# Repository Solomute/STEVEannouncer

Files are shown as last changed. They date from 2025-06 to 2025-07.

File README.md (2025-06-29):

If you are here you have probably opened up one of my announce boxes and are trying to fix it.

The buttons and potentiometers are connected to the board via JST PH 2mm headers. You can buy pre-terminated PH cables from many electronics suppliers, including Amazon. JST makes many models of connector, ensure you are buying the PH.

The buttons are SPST NO. I use a Cherry MX mechanical keyboard switch, the top panel cutout is 0.55" square for a Cherry MX or compatible switch to snap into. Many other brands of mechanical keyboard switches are also designed to snap into the same cutout. Simply search the web for "mechanical keyboard switch."

The potentiometers are 10k linear. Do not use a pot with a value other than 10k. Do not use an "audio" or "log" taper pot. The longest-life pots as of the time of this writing use conductive plastic as the resistance element. Avoid carbon. The front panel cutouts for the pots are sized for a standard 6mm diameter shaft. 1/4" diameter shafts should fit too. For knob compatibility get a pot with a 6mm 18T knurled shaft. If you get some other size, or a flatted-D shaft, you're on your own for knobs.

I used a P160KN-0QD15B10K from TT Electronics, but compatibile parts are available from many manufacturers.

My recommendation is that if you are using these boxes in a production environment, you keep a few extra potentiometers and buttons around pre-wired with JSTs. This way, if a pot or button starts dying, you can swap it out in only a couple of minutes. Maybe even during a commercial break!

No audio flows through the buttons or pots. The box will pass audio with a failed switch. A failed pot will cause the headphone to mute, though in practice, the headphone circuit should keep working flawlessly with pots that are degraded well past the point where they would start sounding "scratchy" if audio were passing directly through them.

XLR Input (female) connectors are Neutrik NC3FAH2. XLR Output (male) connectors are Neutrik NC3MAH. 1/4" TRS headphone connectors are Neutrik NRJ6HF. The DC power input is Switchcraft L721RALP.

Neutrik makes many connectors which are electrically and mechanically compatible with the above, and they all should work. For an alternative to the Switchcraft part, you could use a panel-mounted barrel jack and simply run wires off it into the PCB if necessary.

I strongly recommend a *threaded* barrel jack, and power supplies with *threaded* barrel plugs. Being able to lock the power connector is the reason I used a barrel jack instead of a USB plug for DC power.

For more esoteric repairs, consult the schematics. If THAT Corp or Texas Instruments have gone out of business by the time you read this, God help you. Most other parts on the board are generic, but hi-fi audio parts and switching regulators are hard to multi-source, unfortunately.

Design files for the enclosure are also included - You might be able to get away with 3D printing it, but I recommend using SendCutSend to have it cut and bent out of sheet metal with PCB standoffs inserted. Use 6mm M3x0.5 standoffs. OSHCut is talking about adding hardware insertion to their services, so they might be an option as well by the time you read this.

Good luck!

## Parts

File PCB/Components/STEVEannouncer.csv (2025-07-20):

Reference | Qty | Value | Footprint | Mouser Part Number
C302,C318,C319,C320,C321,C403,C404,C407,C408,C416,C417 | 11 | 100p | Capacitor_SMD:C_0402_1005Metric | 791-0402N101K160CT
C303,C304,C328,C329 | 4 | 470p | Capacitor_SMD:C_0402_1005Metric | 80-C0402C471K5R
C205,C206,C209,C301,C308,C309,C310,C311,C312,C313,C314,C315,C322,C323,C324,C325,C326,C405,C406,C410,C411,C412,C413,C414,C415 | 25 | 100n | Capacitor_SMD:C_0402_1005Metric | 81-GRM155R62A104KE4D
C203,C204 | 2 | 2.2u | Capacitor_SMD:C_0603_1608Metric | 81-GRT188R61H225KE3D
C316,C317,C327 | 3 | 10u | Capacitor_SMD:C_0603_1608Metric | 187-CL10A106KP8NNWC
L201,L202 | 2 | 18u | STEVEannouncer:Inductor 3012 | 652-SRN3015BTA-180M
C207,C208 | 2 | 22u | Capacitor_SMD:C_1206_3216Metric | 791-1206X226K100CT
C305,C306 | 2 | 22u | Capacitor_SMD:CP_Elec_6.3x7.7 | 647-UCD1J220MCL1GS
C307 | 1 | 100u | Capacitor_SMD:C_1206_3216Metric | 81-GRM31CR60J107KE8L
C202 | 1 | 1000u | Capacitor_SMD:CP_Elec_16x17.5 | 667-EEV-FK1H102M
R201,R413 | 2 | 1Meg | Resistor_SMD:R_0402_1005Metric | 603-RC0402FR-7W1ML
R204,R301,R302 | 3 | 10 | Resistor_SMD:R_1206_3216Metric | 652-CR1206-JW-100ELF
R306,R319,R320 | 3 | 100 | Resistor_SMD:R_0402_1005Metric | 652-CR0402FX-1000GLF
R209,R303,R304,R315,R316,R317,R318 | 7 | 1k | Resistor_SMD:R_0402_1005Metric | 708-RMCF0402FT1K00
R403,R404 | 2 | 6.8k | Resistor_SMD:R_0402_1005Metric | 652-CR0402FX-6801GLF
R211,R321,R322,R410 | 4 | 10k | Resistor_SMD:R_0402_1005Metric | 652-CR0402FX-1002GLF
RV401,RV402 | 2 | 10k | STEVEannouncer:Pot | 858-P160KN0QD15B10K
R203,R205,R206,R305,R307,R308,R311,R312,R313,R314,R401,R402,R411,R412 | 14 | 20k | Resistor_SMD:R_0402_1005Metric | 603-RC0402FR-1320KL
R207,R208,R210,R407,R408,R409 | 6 | 80.6k | Resistor_SMD:R_0402_1005Metric | 652-CR0402-FX8062GLF
R202,R309,R310,R405,R406 | 5 | 330k | Resistor_SMD:R_0402_1005Metric | 603-RC0402FR-13330KL
C201,C401,C402,C409 | 4 | 1u/50V | Capacitor_SMD:C_0402_1005Metric | 81-GRM155R61H105KE5D
J201 | 1 | Barrel_Jack_Switch | STEVEannouncer:Barrel Jack | 502-L721RALP
D304,D305,D401,D402,D403,D404,D405 | 7 | BAS716 | Diode_SMD:D_SOD-523 | 771-BAS716-T/R
D301,D307,D308 | 3 | BAS3007 | Package_TO_SOT_SMD:SOT-143 | 726-BAS3007A-RPPE6
Q201 | 1 | BC847 | Package_TO_SOT_SMD:SOT-523 | 621-BC847CT-7-F
Q202 | 1 | BCV49 | STEVEannouncer:SOT-89-3 | 771-BCV49135
J303,J304 | 2 | Conn_01x02 | Connector_JST:JST_PH_B2B-PH-SM4-TB_1x02-1MP_P2.00mm_Vertical | 306-B2BPHSM4TBLFSN
J403,J405 | 2 | Conn_01x03 | Connector_JST:JST_PH_B3B-PH-SM4-TB_1x03-1MP_P2.00mm_Vertical | 306-B3BPHSM4TBLFSN
D202,D203,D306 | 3 | D_Schottky | Diode_SMD:D_SOD-523 | 755-RB510SM-40T2R
D201,D302,D303 | 3 | DFLZ5V6 | Diode_SMD:D_PowerDI-123 | 621-DFLZ5V6-7
FB301,FB302,FB303,FB304,FB401,FB402 | 6 | FerriteBead | Inductor_SMD:L_0402_1005Metric | 673-BBSY100505700Y00
D204 | 1 | LED | LED_SMD:LED_0603_1608Metric | 859-LTST-C191KRKT
U201,U202 | 2 | LV3842 | STEVEannouncer:SOT-23-6 | 595-LV3842XDBVR
J306,J307 | 2 | NC3MAH | STEVEannouncer:NC3MAH | 568-NC3MAH
J301,J401 | 2 | NC3FAH2 | STEVEannouncer:NC3FAH2 | 568-NC3FAH-2
J406,J407 | 2 | NRJ6HF | STEVEannouncer:NRJ6HF | 550-20311
U305 | 1 | OPA202 | Package_TO_SOT_SMD:SOT-23-5 | 595-OPA202IDBVR
U403 | 1 | OPA1622 | STEVEannouncer:OPA1622 | 595-OPA1622IDRCT
U302,U402 | 2 | OPA1678 | STEVEannouncer:WSON-8-1EP_3x3mm_P0.5mm_EP1.2x2mm_ThermalVias | 595-OPA1678IDRGR
B401,B402 | 2 | Plastic Nut |  | 550-1005
SW301,SW302 | 2 | SW_SPST | STEVEannouncer:SW_choc_v1_1u | 540-MX1A-C1NN
U303 | 1 | THAT1512 | Package_SO:SO-8_3.9x4.9mm_P1.27mm | 887-1512S08-U
U304 | 1 | THAT1646 | Package_SO:SO-8_3.9x4.9mm_P1.27mm | 887-1646S08-U
U401 | 1 | THAT2162 | Package_SO:QSOP-16_3.9x4.9mm_P0.635mm | 887-2162Q16-U
U301 | 1 | TMUX6236 | Package_SO:TSSOP-16_4.4x5mm_P0.65mm | 595-TMUX6236PWR

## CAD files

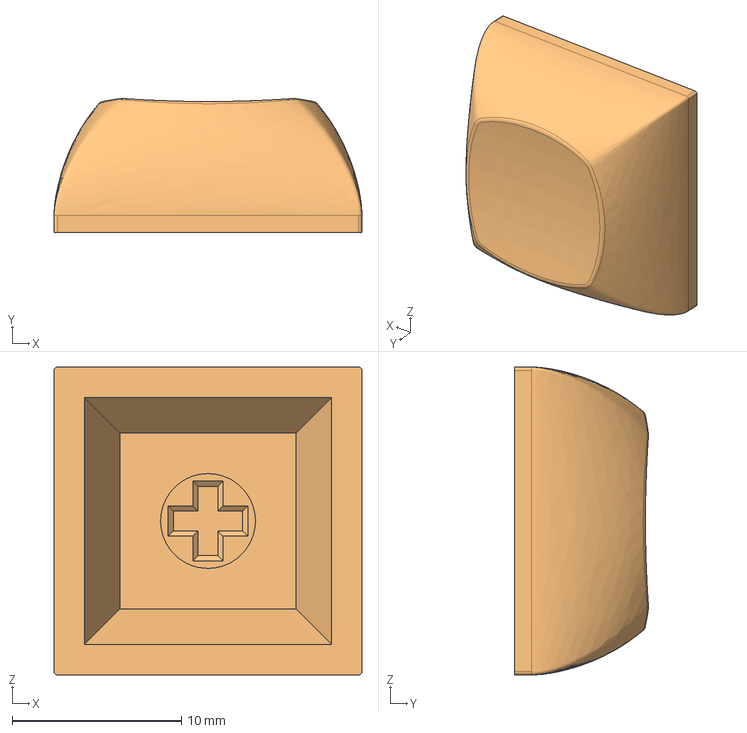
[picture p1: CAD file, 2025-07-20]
Enclosure/DSA_1u.step
18.2 x 7.91 x 18.2 mm

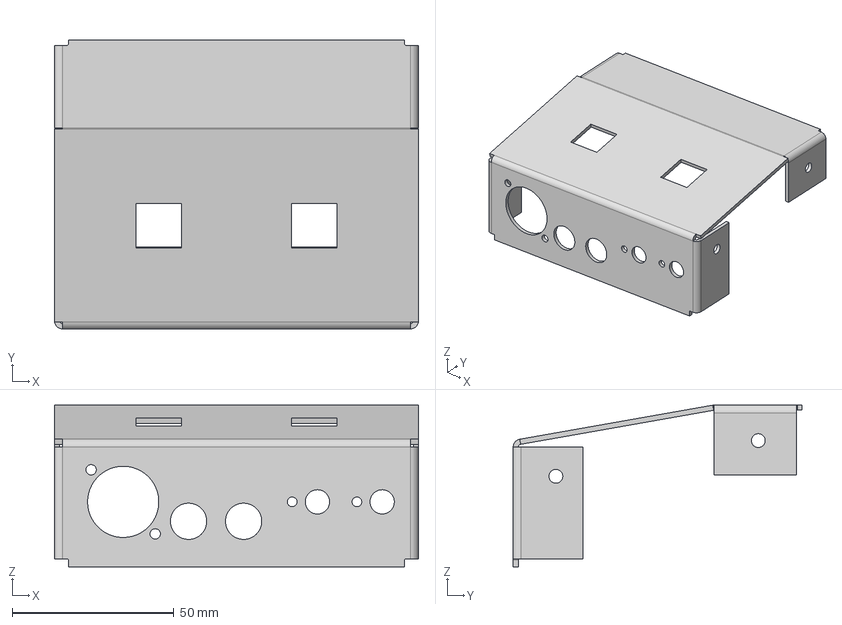
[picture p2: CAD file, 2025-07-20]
Enclosure/Enclosure Top.step
112.4 x 89.2 x 50.0 mm

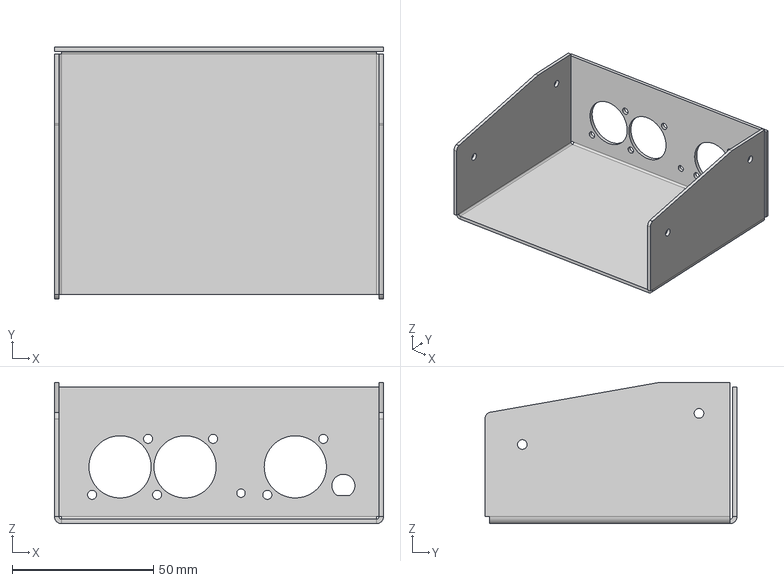
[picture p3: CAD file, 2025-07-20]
Enclosure/Enclosure Bottom.step
116.4 x 89.2 x 50.0 mm

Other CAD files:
Enclosure/Enclosure Bottom.dxf
Enclosure/Enclosure Top.dxf

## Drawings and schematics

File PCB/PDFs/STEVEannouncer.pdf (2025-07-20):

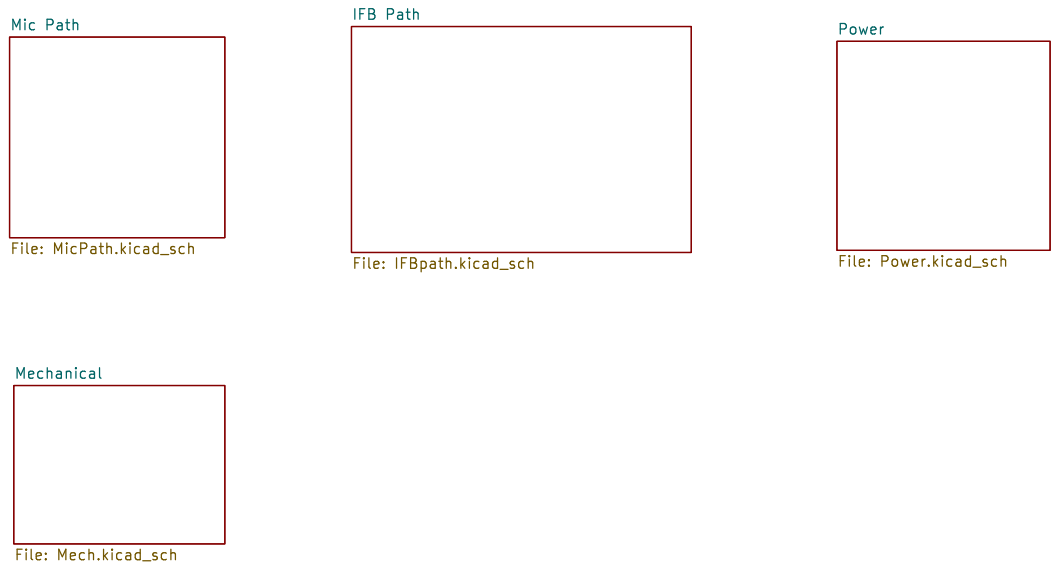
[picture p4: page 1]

Id: 1/5 Title: File: STEVEannouncer.kicad_sch Sheet: / Mechanical File: Mech.kicad_sch

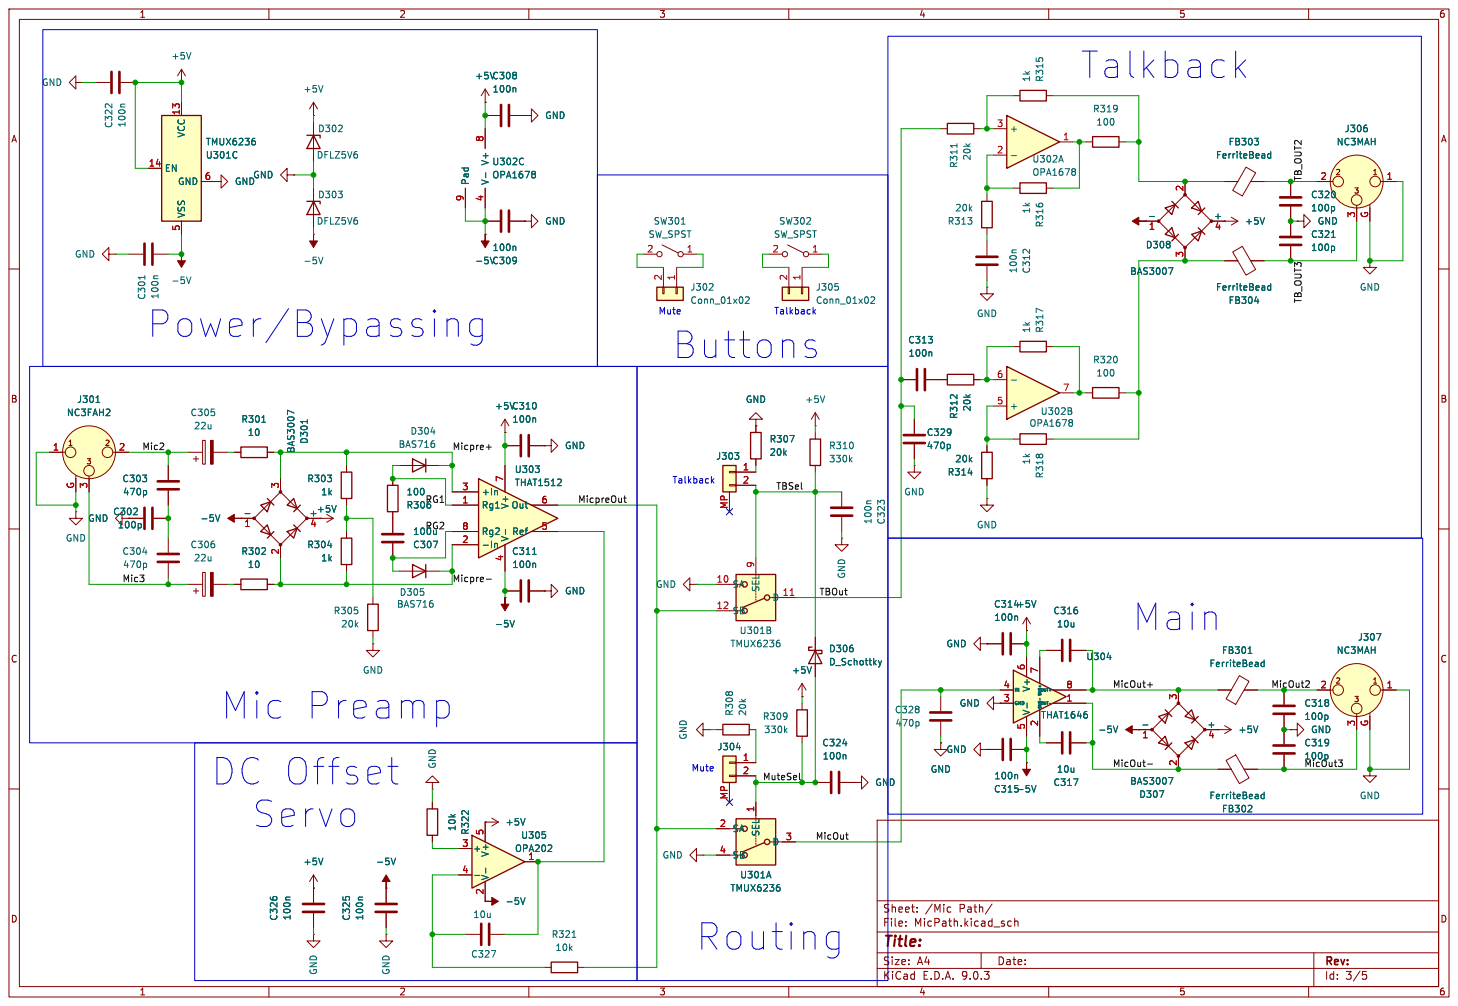
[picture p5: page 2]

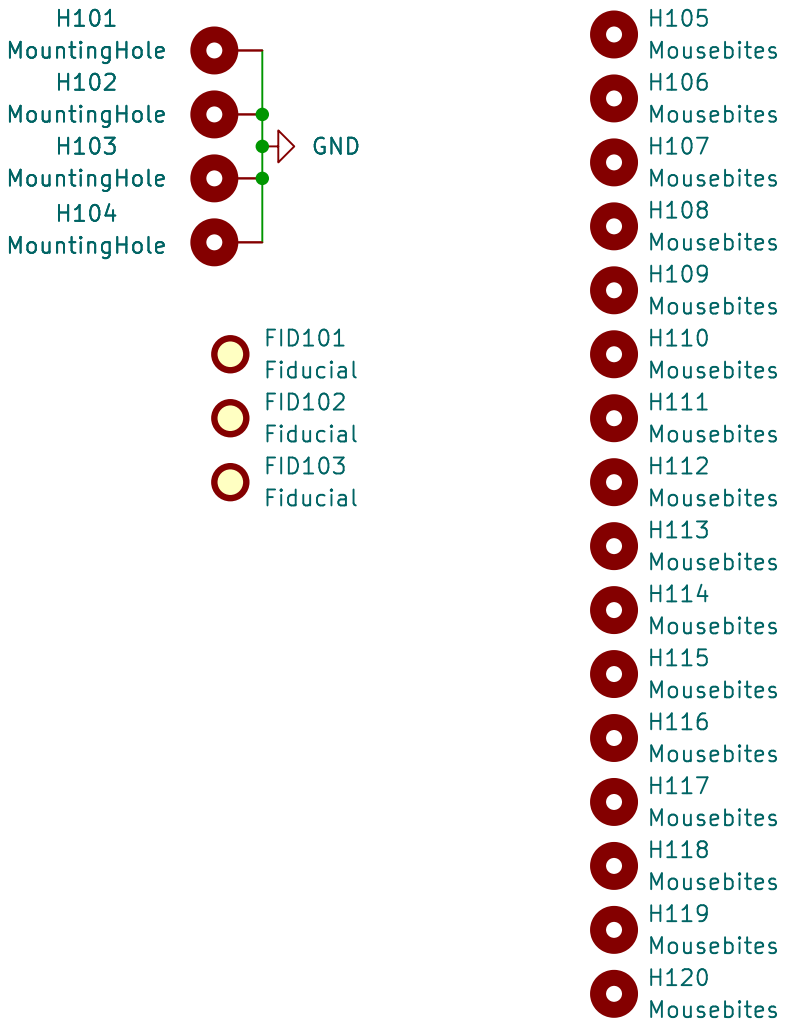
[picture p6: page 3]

H101 MountingHole H104 MountingHole H102 MountingHole H103 MountingHole

Id: 5/5 Title: File: Mech.kicad_sch Sheet: /Mechanical/

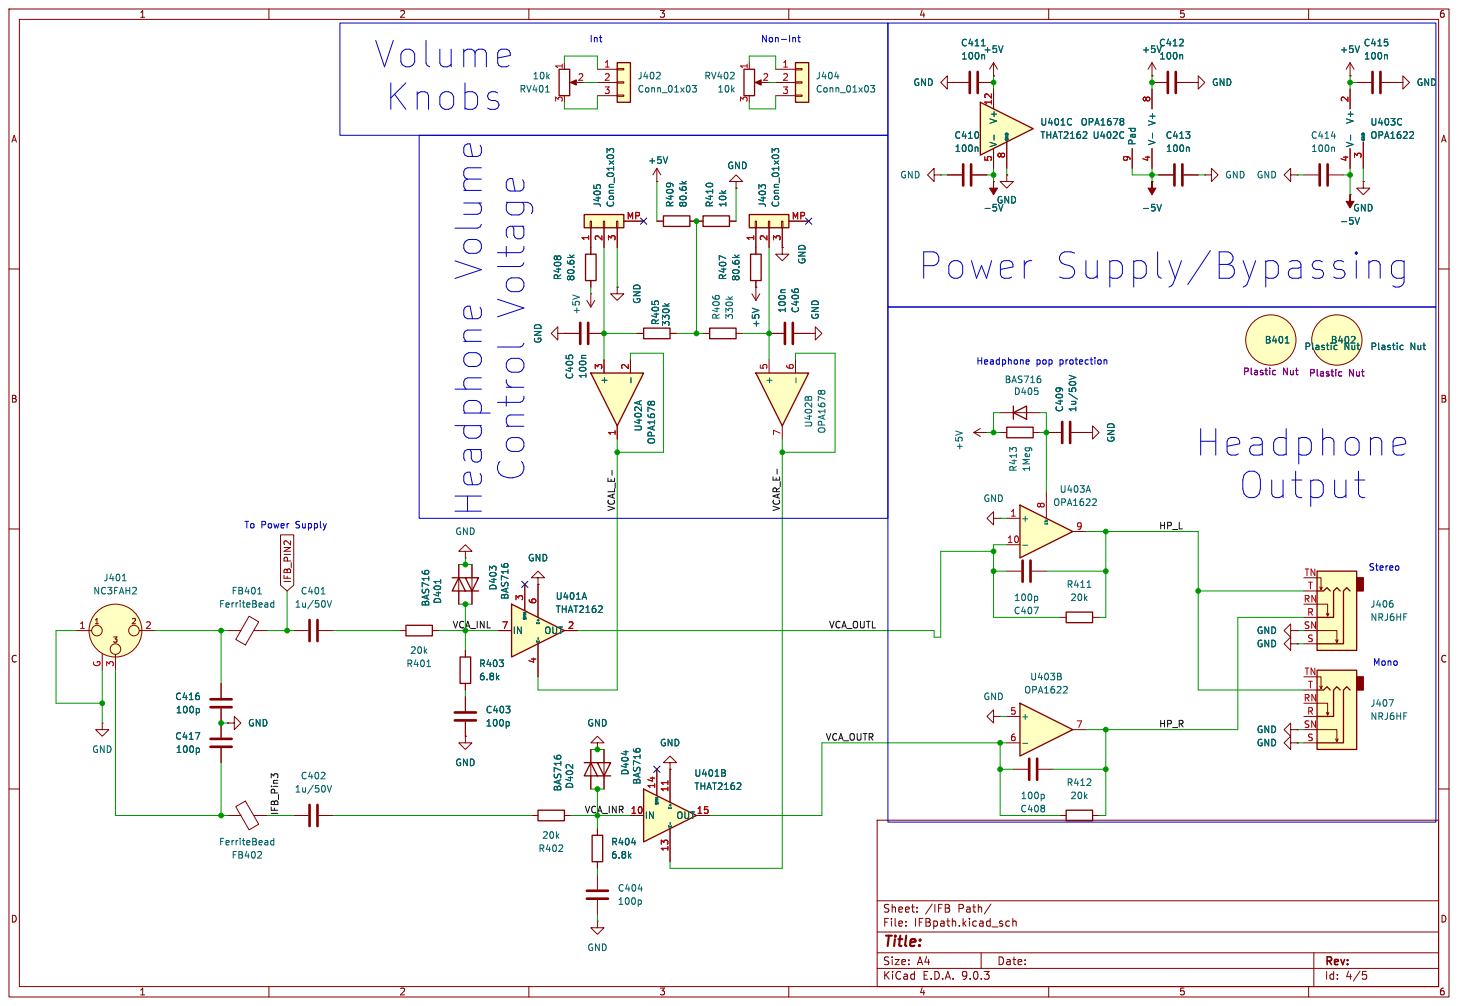
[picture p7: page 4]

Stereo Headphone pop protection Headphone Volume Control Voltage

3 MP GND R410 10k GND GND GND GND

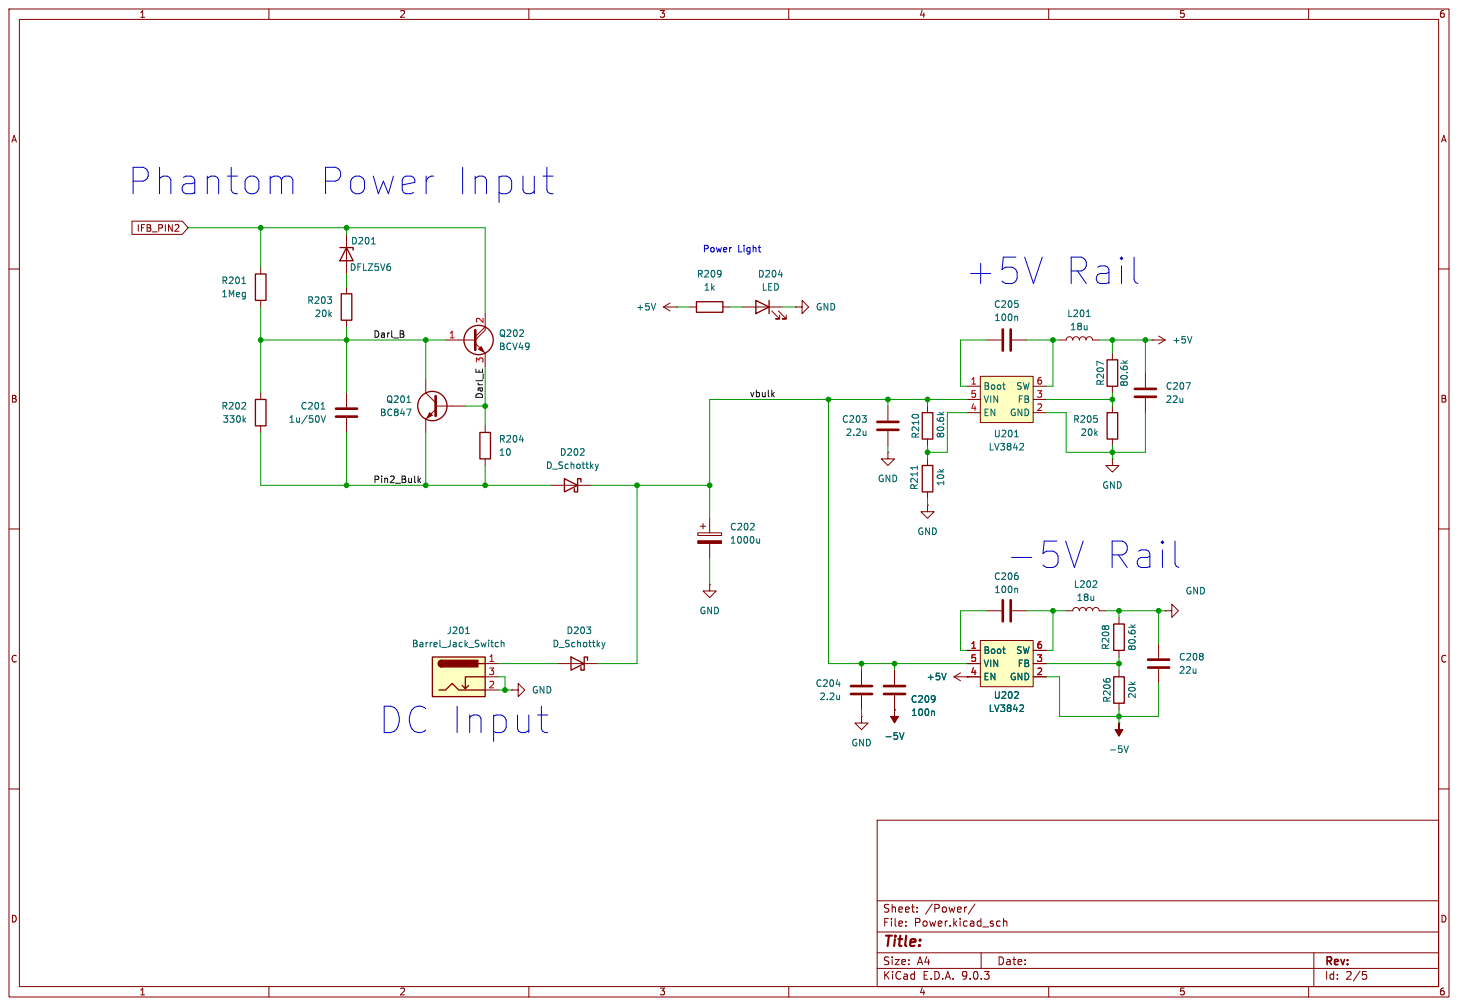
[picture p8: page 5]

2 3 Q202 BCV49 Boot 1 VIN 5 EN 4 SW 6 FB 3 GND 2 U201

Id: 2/5 Title: File: Power.kicad_sch Sheet: /Power/

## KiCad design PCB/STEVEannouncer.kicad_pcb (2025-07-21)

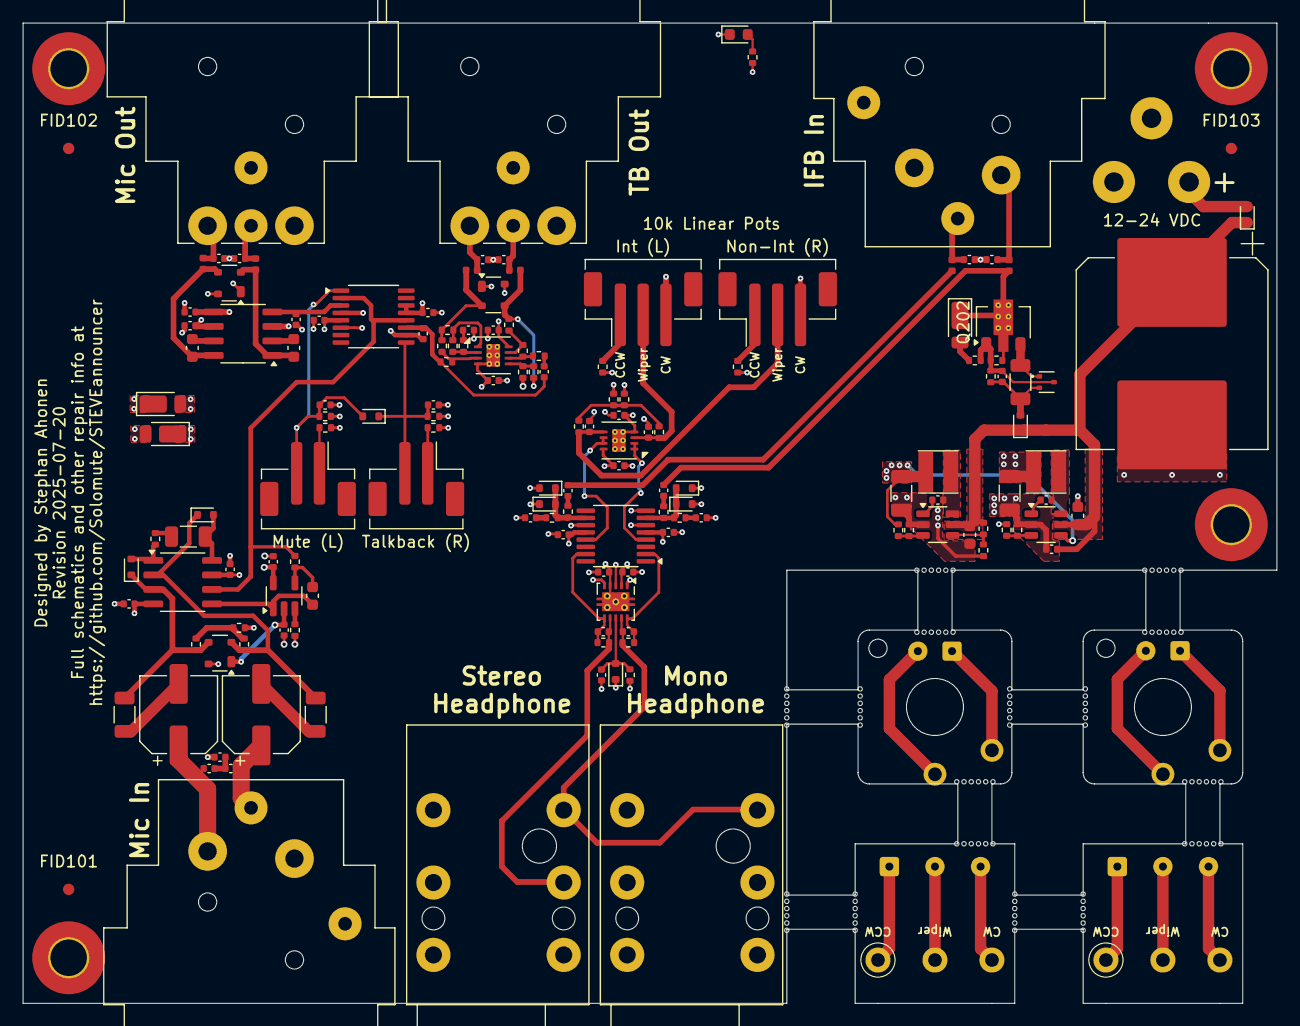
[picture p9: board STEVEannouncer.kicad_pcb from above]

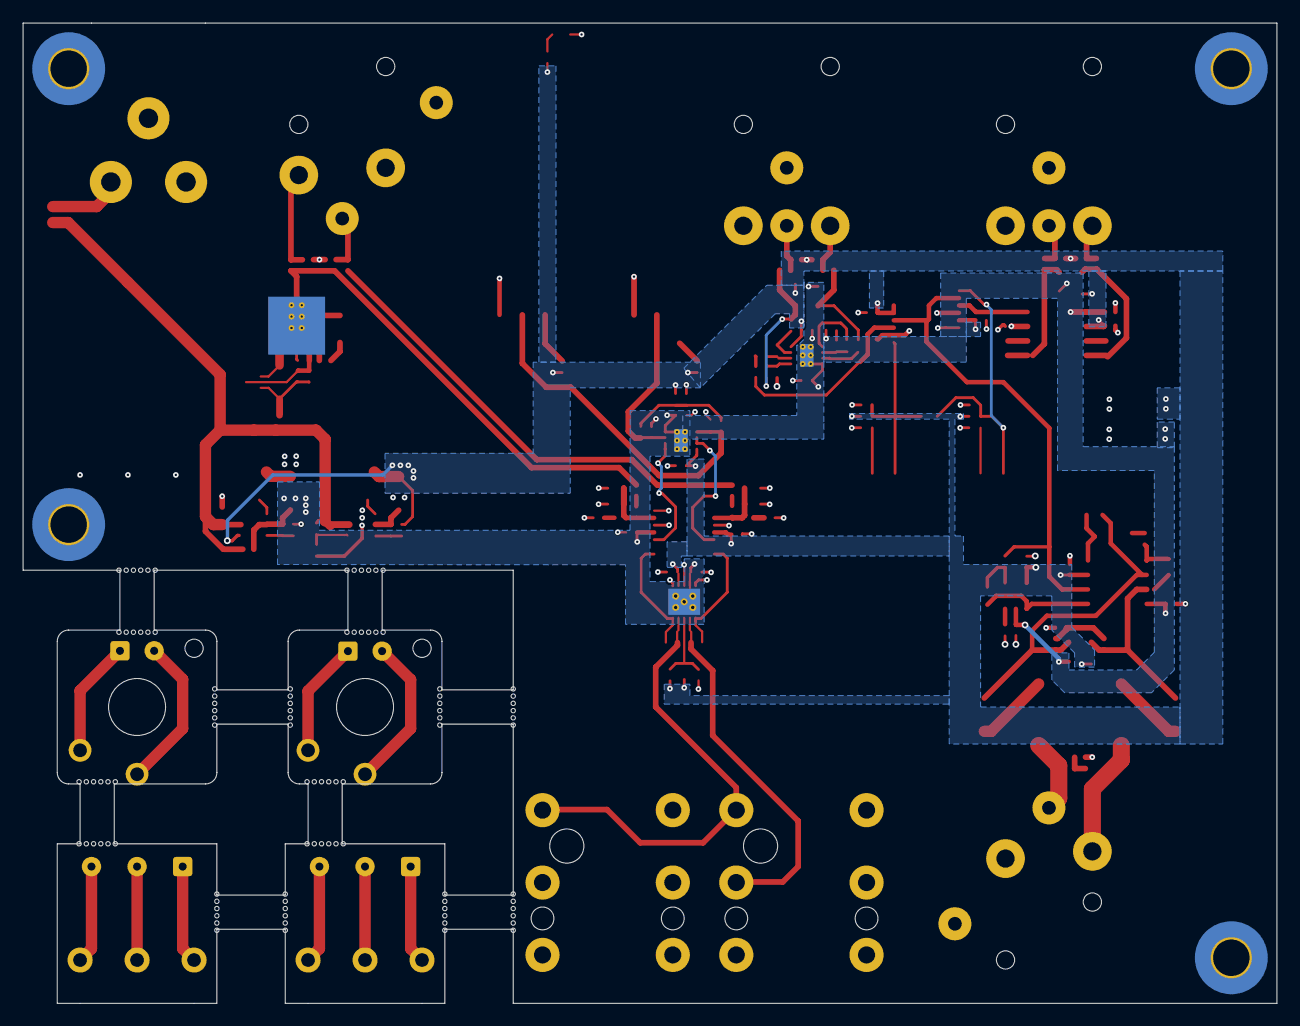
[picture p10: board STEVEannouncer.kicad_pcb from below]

Board: 4 copper layers, 110.0 x 86.0 mm, 180 parts (2 on the bottom side), 88 nets.

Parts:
C201, C401, C402, C409: 1u/50V; C_0402_1005Metric
C202: 1000u; CP_Elec_16x17.5
C203, C204: 2.2u; C_0603_1608Metric
C205, C206, C209, C301, C308, C309, C310, C311, C312, C313, C314, C315, C322, C323, C324, C325, C326, C405, C406, C410, C411, C412, C413, C414, C415: 100n; C_0402_1005Metric
C207, C208: 22u; C_1206_3216Metric
C302, C318, C319, C320, C321, C403, C404, C407, C408, C416, C417: 100p; C_0402_1005Metric
C303, C304, C328, C329: 470p; C_0402_1005Metric
C305, C306: 22u; CP_Elec_6.3x7.7
C307: 100u; C_1206_3216Metric
C316, C317, C327: 10u; C_0603_1608Metric
D201, D302, D303: DFLZ5V6; D_PowerDI-123
D202, D203, D306: D_Schottky; D_SOD-523
D204: LED; LED_0603_1608Metric
D301, D307, D308: BAS3007; SOT-143
D304, D305, D401, D402, D403, D404, D405: BAS716; D_SOD-523
FB301, FB302, FB303, FB304, FB401, FB402: FerriteBead; L_0402_1005Metric
FID101, FID102, FID103: Fiducial; Fiducial_1mm_Mask3mm
H101, H102, H103, H104: MountingHole; MountingHole_3.2mm_M3_Pad_TopBottom
H105, H106, H107, H108, H109, H110, H111, H112, H113, H114, H115, H116, H117, H118, H119, H120: Mousebites
J201: Barrel_Jack_Switch; Barrel Jack
J301, J401: NC3FAH2
J302, J305: Conn_01x02; SolderWire-0.15sqmm_1x02_P4mm_D0.5mm_OD1.5mm
J303, J304: Conn_01x02; JST_PH_B2B-PH-SM4-TB_1x02-1MP_P2.00mm_Vertical
J306, J307: NC3MAH
J402, J404: Conn_01x03; SolderWire-0.15sqmm_1x03_P4mm_D0.5mm_OD1.5mm
J403, J405: Conn_01x03; JST_PH_B3B-PH-SM4-TB_1x03-1MP_P2.00mm_Vertical
J406, J407: NRJ6HF
L201, L202: 18u; Inductor 3012
Q201: BC847; SOT-523
Q202: BCV49; SOT-89-3
R201, R413: 1Meg; R_0402_1005Metric
R202, R309, R310, R405, R406: 330k; R_0402_1005Metric
R203, R205, R206, R305, R307, R308, R311, R312, R313, R314, R401, R402, R411, R412: 20k; R_0402_1005Metric
R204, R301, R302: 10; R_1206_3216Metric
R207, R208, R210, R407, R408, R409: 80.6k; R_0402_1005Metric
R209, R303, R304, R315, R316, R317, R318: 1k; R_0402_1005Metric
R211, R321, R322, R410: 10k; R_0402_1005Metric
R306, R319, R320: 100; R_0402_1005Metric
R403, R404: 6.8k; R_0402_1005Metric
RV401, RV402: 10k; Pot
SW301, SW302: SW_SPST; SW_choc_v1_1u
U201, U202: LV3842; SOT-23-6
U301: TMUX6236; TSSOP-16_4.4x5mm_P0.65mm
U302, U402: OPA1678; WSON-8-1EP_3x3mm_P0.5mm_EP1.2x2mm_ThermalVias
U303: THAT1512; SO-8_3.9x4.9mm_P1.27mm
U304: THAT1646; SO-8_3.9x4.9mm_P1.27mm
U305: OPA202; SOT-23-5
U401: THAT2162; QSOP-16_3.9x4.9mm_P0.635mm
U403: OPA1622

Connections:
+5V: C207.1, C308.2, C310.1, C314.2, C322.1, C326.2, C411.1, C412.1, C415.1, D301.4 (+), D302.1 (K), D307.4 (+), D308.4 (+), D405.1 (K), L201.2, R207.2, R209.1, R309.2, R310.2, R407.1, R408.1, R409.1, R413.2, U202.4 (EN), U301.13 (VCC), U301.14 (EN), U302.8 (V+), U303.7 (V+), U304.6 (V+), U305.5 (V+), U401.12 (V+), U402.8 (V+), U403.2 (V+)
-5V: C208.2, C209.1, C301.1, C309.2, C311.1, C315.2, C325.2, C410.2, C413.2, C414.2, D301.1 (-), D303.2 (A), D307.1 (-), D308.1 (-), R206.2, U202.2 (GND), U301.5 (VSS), U302.4 (V-), U302.9 (Pad), U303.4 (V-), U304.5 (V-), U305.2 (V-), U401.5 (V-), U402.4 (V-), U402.9 (Pad), U403.4 (V-), U403.11 (V-)
/IFB Path/HP_L: C407.2, J406.T, J407.T, R411.2, U403.9
/IFB Path/HP_R: C408.2, J406.R, R412.2, U403.7
/IFB Path/IFB_Pin3: C402.1, FB402.2
/IFB Path/VCAL_E-: U401.4 (E-), U402.1, U402.2 (-)
/IFB Path/VCAR_E-: U401.13 (E-), U402.6 (-), U402.7
/IFB Path/VCA_INL: D401.2 (A), D403.1 (K), R401.2, R403.1, U401.7 (IN)
/IFB Path/VCA_INR: D402.2 (A), D404.1 (K), R402.2, R404.1, U401.10 (IN)
/IFB Path/VCA_OUTL: C407.1, R411.1, U401.2 (OUT), U403.10 (-)
/IFB Path/VCA_OUTR: C408.1, R412.1, U401.15 (OUT), U403.6 (-)
/Mic Path/Mic2: C303.1, C305.1, J301.2
/Mic Path/Mic3: C304.2, C306.1, J301.3
/Mic Path/MicOut: C328.1, U301.3 (D), U304.4 (IN)
/Mic Path/MicOut2: C318.1, FB301.2, J307.2
/Mic Path/MicOut3: C319.2, FB302.2, J307.3
/Mic Path/MicOut+: C316.2, D307.3, FB301.1, U304.8 (OUT+)
/Mic Path/MicOut-: C317.2, D307.2, FB302.1, U304.1 (OUT-)
/Mic Path/Micpre+: D301.3, D304.1 (K), R301.1, R303.1, U303.3 (+In)
/Mic Path/Micpre-: D301.2, D305.1 (K), R302.1, R304.2, U303.2 (-In)
/Mic Path/MicpreOut: R321.1, U301.2 (SA), U301.12 (SB), U303.6 (Out)
/Mic Path/MuteSel: C324.2, D306.2 (A), J304.2, R309.1, U301.1 (SEL)
/Mic Path/RG1: D304.2 (A), R306.2, U303.1 (Rg1)
/Mic Path/RG2: C307.2, D305.2 (A), U303.8 (Rg2)
/Mic Path/TBOut: C313.2, C329.1, R311.1, U301.11 (D)
/Mic Path/TBSel: C323.2, D306.1 (K), J303.2, R310.1, U301.9 (SEL)
/Mic Path/TB_OUT2: C320.1, FB303.2, J306.2
/Mic Path/TB_OUT3: C321.2, FB304.2, J306.3
/Power/Darl_B: C201.1, Q201.3 (C), Q202.1 (B), R201.2, R202.1, R203.2
/Power/Darl_E: Q201.1 (B), Q202.3 (E), R204.1
/Power/Pin2_Bulk: C201.2, D202.2 (A), Q201.2 (E), R202.2, R204.2
/Power/vbulk: C202.1, C203.1, C204.1, C209.2, D202.1 (K), D203.1 (K), R210.2, U201.5 (VIN), U202.5 (VIN)
GND: C202.2, C203.2, C204.2, C207.2, C208.1, C301.2, C302.1, C308.1, C309.1, C310.2, C311.2, C312.1, C314.1, C315.1, C318.2, C319.1, C320.2, C321.1, C322.2, C323.1, C324.1, C325.1, C326.1, C328.2, C329.2, C403.2, C404.2, C405.2, C406.2, C409.1, C410.1, C411.2, C412.2, C413.1, C414.1, C415.2, C416.2, C417.1, D204.1 (K), D302.2 (A), D303.1 (K), D401.1 (K), D402.1 (K), D403.2 (A), D404.2 (A), H101.1, H102.1, H103.1, H104.1, J201.2, J201.3, J301.1, J301.G, J306.1, J306.G, J307.1, J307.G, J401.1, J401.G, J403.3, J405.3, J406.S, J406.SN, J407.S, J407.SN, L202.2, R205.2, R208.2, R211.1, R305.2, R307.2, R308.2, R314.1, R322.2, R410.1, U201.2 (GND), U301.4 (SB), U301.6 (GND), U301.10 (SA), U304.3 (GND), U401.6 (E+), U401.8 (GND), U401.11 (E+), U403.1 (+), U403.3 (GND), U403.5 (+)
IFB_PIN2: C401.1, D201.1 (K), FB401.2, Q202.2 (C), R201.1
unnamed: C302.2, C303.2, C304.1
unnamed: C305.2, R301.2
unnamed: C306.2, R302.2
unnamed: C307.1, R306.1
unnamed: C312.2, R313.1
unnamed: C313.1, R312.1
unnamed: C401.2, R401.1
unnamed: C402.2, R402.1
unnamed: C403.1, R403.2
unnamed: C404.1, R404.2
unnamed: C416.1, FB401.1, J401.2
unnamed: C417.2, FB402.1, J401.3
unnamed: D201.2 (A), R203.1
unnamed: D203.2 (A), J201.1
unnamed: D204.2 (A), R209.2
unnamed: D308.2, FB303.1, R315.1, R319.2
unnamed: D308.3, FB304.1, R318.1, R320.2
unnamed: C409.2, D405.2 (A), R413.1, U403.8 (EN)
unnamed: J302.1, SW301.1 (A)
unnamed: J302.2, SW301.2 (B)
unnamed: J303.1, R307.1
unnamed: J304.1, R308.1
unnamed: J305.1, SW302.1 (A)
unnamed: J305.2, SW302.2 (B)
unnamed: J402.1, RV401.1
unnamed: J402.2, RV401.2
unnamed: J402.3, RV401.3
unnamed: J403.1, R407.2
unnamed: C406.1, J403.2, R406.2, U402.5 (+)
unnamed: J404.1, RV402.1
unnamed: J404.2, RV402.2
unnamed: J404.3, RV402.3
unnamed: J405.1, R408.2
unnamed: C405.1, J405.2, R405.1, U402.3 (+)
unnamed: R303.2, R304.1, R305.1
unnamed: R316.1, R319.1, U302.1
unnamed: R317.1, R320.1, U302.7
unnamed: R405.2, R406.1, R409.2, R410.2
unnamed: C205.1, U201.1 (Boot)
unnamed: R210.1, R211.2, U201.4 (EN)
unnamed: R205.1, R207.1, U201.3 (FB)
unnamed: C205.2, L201.1, U201.6 (SW)
unnamed: C206.1, U202.1 (Boot)
unnamed: R206.1, R208.1, U202.3 (FB)
unnamed: C206.2, L202.1, U202.6 (SW)
unnamed: R311.2, R315.2, U302.3 (+)
unnamed: R313.2, R316.2, U302.2 (-)
unnamed: R314.2, R318.2, U302.5 (+)
unnamed: R312.2, R317.2, U302.6 (-)
unnamed: C327.2, U303.5 (Ref), U305.1
unnamed: C316.1, U304.7 (SNS+)
unnamed: C317.1, U304.2 (SNS-)
unnamed: R322.1, U305.3 (+)
unnamed: C327.1, R321.2, U305.4 (-)

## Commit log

2025-06-28 Moar Progress
    [IFBpath.kicad_sch, MicPath.kicad_sch, STEVEannouncer.kicad_pcb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]
2025-06-29 Even more more progress
    [IFBpath.kicad_sch, MicPath.kicad_sch, STEVEannouncer.kicad_pcb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]
2025-06-30 I think I can fab this????
    [IFBpath.kicad_sch, MicPath.kicad_sch, Power.kicad_sch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]
2025-07-01 There, I ordered it
    [MicPath.kicad_sch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]
2025-07-04 Enclosure files
    [DSA_1u.step, Enclosure Bottom.dxf, Enclosure Bottom.step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]
2025-07-20 Rev 2025-07-20
    [IFBpath.kicad_sch, Mech.kicad_sch, MicPath.kicad_sch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]
2025-07-20 Tidying up
    [IFBpath.kicad_sch, MicPath.kicad_sch, Power.kicad_sch]
2025-07-20 moar cleaning
    [IFBpath.kicad_sch, MicPath.kicad_sch]
2025-07-21 How did those footprints lose their solder mask?????
    [STEVEannouncer.kicad_pcb]
